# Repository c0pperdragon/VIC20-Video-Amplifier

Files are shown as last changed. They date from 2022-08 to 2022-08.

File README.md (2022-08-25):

# VIC20-Video-Amplifier
Modify the analog video circuit of a VIC 20 to use modern parts

## Project intentions

My main intention here was to learn about the video generation circuitry of the VIC-20
and maybe come up with some way to interface it with a RGBtoHDMI to generate HDMI.

While I did not succeed in reliably quantizing the analog signal back to its digital
form, I did make some improvements on the overall analog circuit. 
 
## Replace original video amplifier with sockets

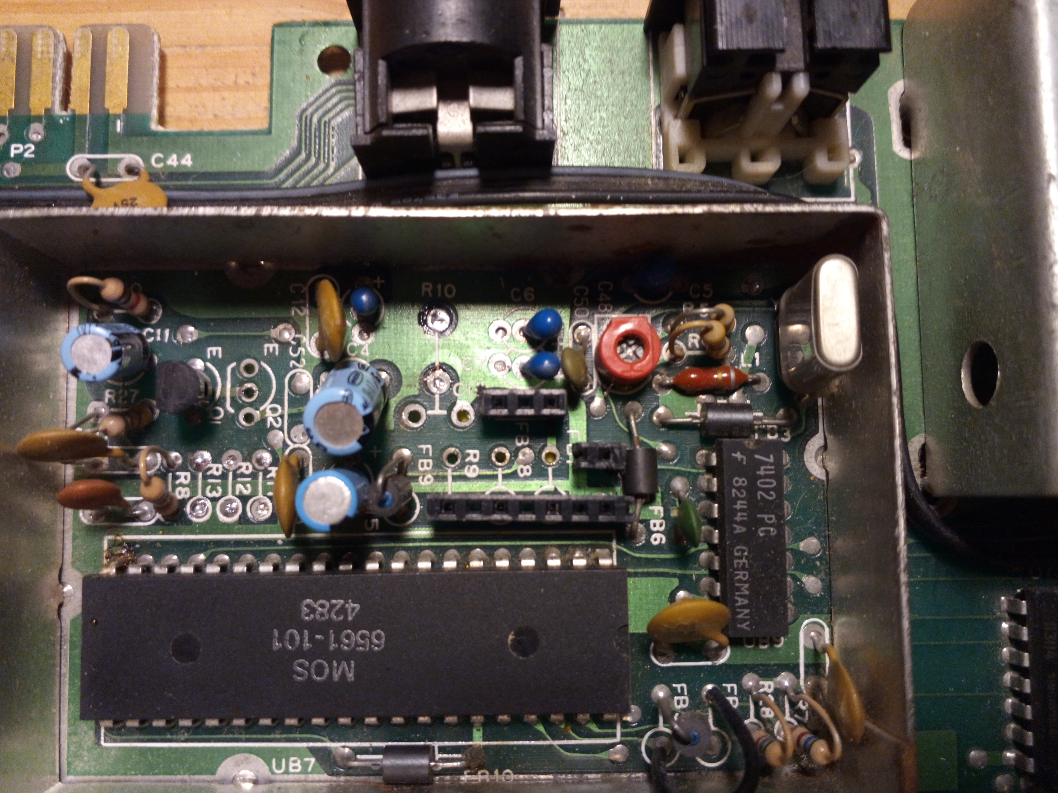
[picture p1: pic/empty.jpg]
Replaced analog parts with pin headers


To make experimenting simpler, I just went and totally removed all components involved
in amplifying the video signal from the VIC. On my board (cost reduced small variant) this is realtively
easy, as the empty contact holes next to the VIC directly carry GND, +5V and both luma and chroma.
These are now broken out with a pin socket (using 4 of the 7 contacts). On the other side sockets are 
prepared to receive 3 signals to be forwarded to the A/V connector on pin 1, 4 and 5. 

## Cabling on the underside

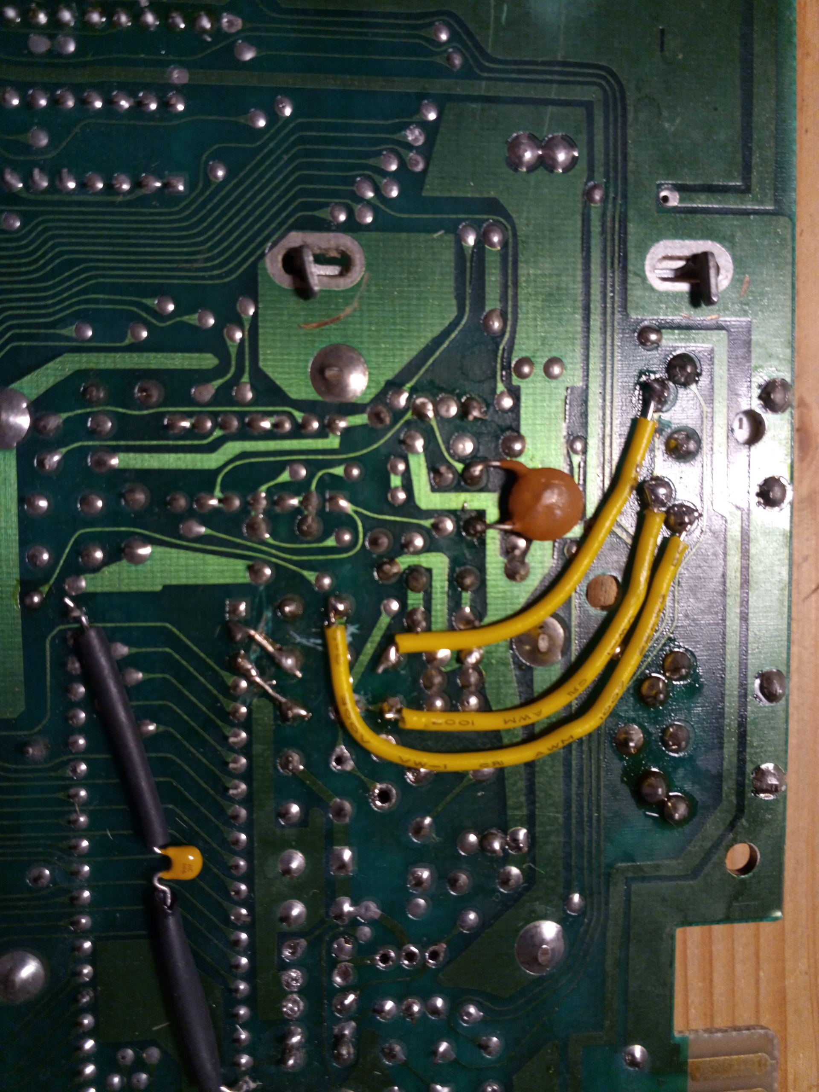
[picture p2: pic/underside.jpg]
Forward signals to the A/V port


Using 3 now unused holes (all parts are removed here so the traces do not matter) the pin sockets
on the front side are forwarded with wires to the A/V connector. Also the PCB trace between 
pin 4 and pin 5 under the connector and between pin 1 and 5V had to be cut. 

## Insert an amplifier PCB

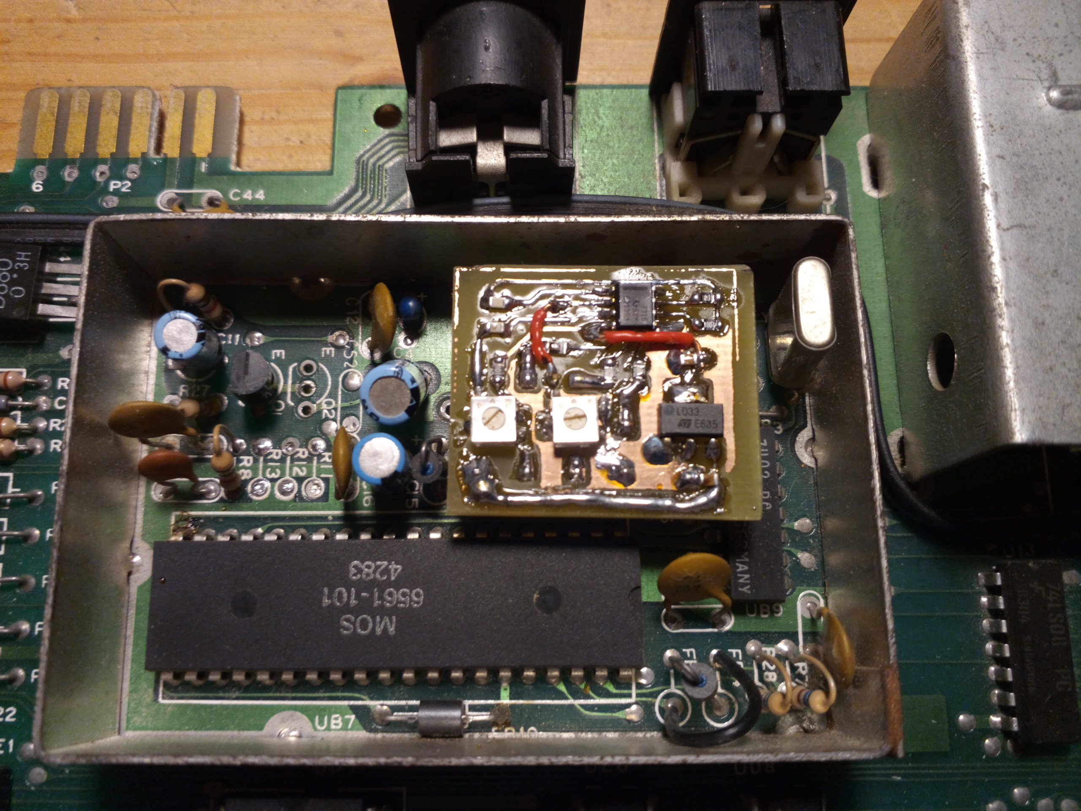
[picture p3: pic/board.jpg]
Home-etched PCB with amplifier


I designed a PCB that carries a modern video amplifier IC and its supporting passive components to
fit the prepared pin sockets. 

Two trimmer potentiometers are provided to independently adjust the brightness and the color saturation.

A voltage regulator is used to get a stable reference voltage to drive the VIC's luma output DAC. 
This should provide the most noise-free signal possible.
 
## Modified A/V pinout

| Pin  | Signal |
| ---- | --- |
| 1 | Luminance |
| 2 | Ground |
| 3 | Audio |
| 4 | Composite |
| 5 | Chroma |

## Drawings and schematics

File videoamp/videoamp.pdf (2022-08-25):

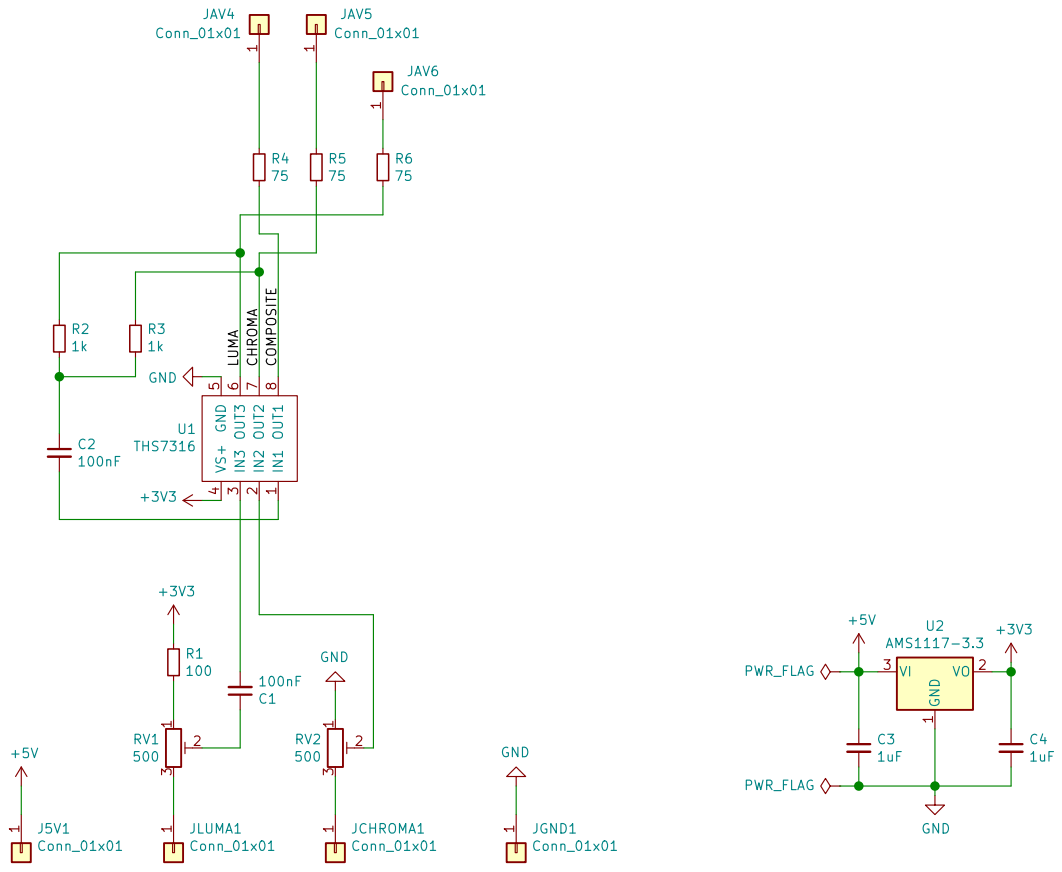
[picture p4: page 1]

File: videoamp.sch Sheet: / IN1

Id: 1/1 Title: VIC-20 Video Amplifier

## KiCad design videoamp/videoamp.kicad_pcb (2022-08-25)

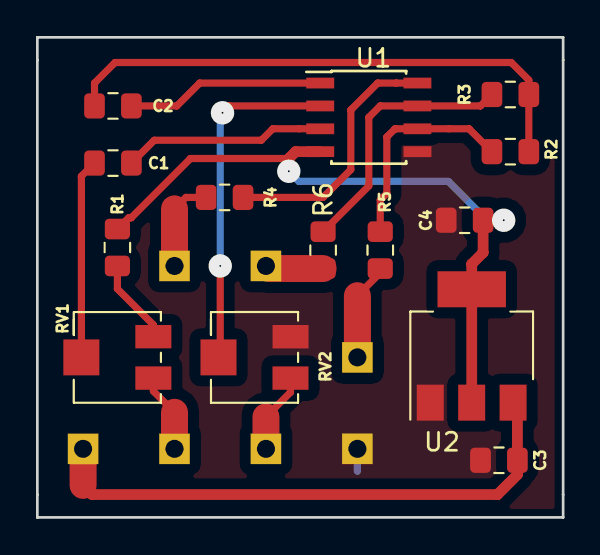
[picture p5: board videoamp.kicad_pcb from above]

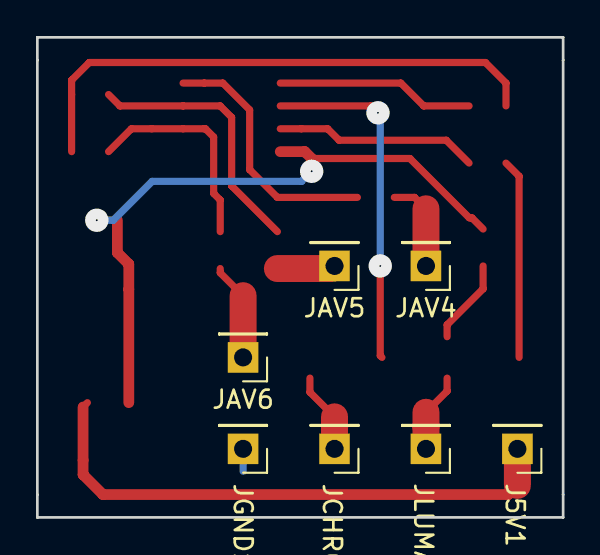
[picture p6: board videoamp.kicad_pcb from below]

Board: 2 copper layers, 29.2 x 26.7 mm, 21 parts (7 on the bottom side), 17 nets.

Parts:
C1, C2: 100nF; C_0805_2012Metric_Pad1.15x1.40mm_HandSolder
C3, C4: 1uF; C_0805_2012Metric_Pad1.15x1.40mm_HandSolder
J5V1: Conn_01x01; PinHeader_1x01_P2.54mm_Vertical
JAV4, JAV5, JAV6: Conn_01x01; PinHeader_1x01_P2.54mm_Vertical
JCHROMA1: Conn_01x01; PinHeader_1x01_P2.54mm_Vertical
JGND1: Conn_01x01; PinHeader_1x01_P2.54mm_Vertical
JLUMA1: Conn_01x01; PinHeader_1x01_P2.54mm_Vertical
R1: 100; R_0805_2012Metric_Pad1.15x1.40mm_HandSolder
R2, R3: 1k; R_0805_2012Metric_Pad1.15x1.40mm_HandSolder
R4, R5, R6: 75; R_0805_2012Metric_Pad1.15x1.40mm_HandSolder
RV1, RV2: 500; Potentiometer_Bourns_3224J_Horizontal
U1: THS7316; SOIC-8_3.9x4.9mm_P1.27mm
U2: AMS1117-3.3; SOT-223-3_TabPin2

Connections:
+3V3: C4.1, R1.1, U1.4, U2.2
+5V: C3.1, J5V1.1, U2.3
/CHROMA: R3.2, R5.2, U1.7
/COMPOSITE: R4.2, U1.8
/LUMA: R2.2, R6.2, U1.6
GND: C3.2, C4.2, JGND1.1, RV2.1, U1.5, U2.1
unnamed: C1.1, RV1.2
unnamed: C1.2, U1.3
unnamed: C2.1, R2.1, R3.1
unnamed: C2.2, U1.1
unnamed: JAV4.1, R4.1
unnamed: JAV5.1, R5.1
unnamed: JAV6.1, R6.1
unnamed: JCHROMA1.1, RV2.3
unnamed: JLUMA1.1, RV1.3
unnamed: R1.2, RV1.1
unnamed: RV2.2, U1.2

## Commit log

2022-01-29 Clean up the PCB a bit
    [videoamp.kicad_pcb, videoamp.sch]
2022-08-25 Redesign board to provide luma/chroma/composite signals on A/V out
    [videoamp.kicad_pcb, videoamp.sch]
